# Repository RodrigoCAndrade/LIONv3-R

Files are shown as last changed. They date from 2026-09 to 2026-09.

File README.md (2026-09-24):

<div align="center">
  Rodrigo Andrade Logo
</div>

<h1 align="center">LIONv3-R Module</h1>

<p align="center">
    
    
    
    
    
</p>

<br>

<p align="center">
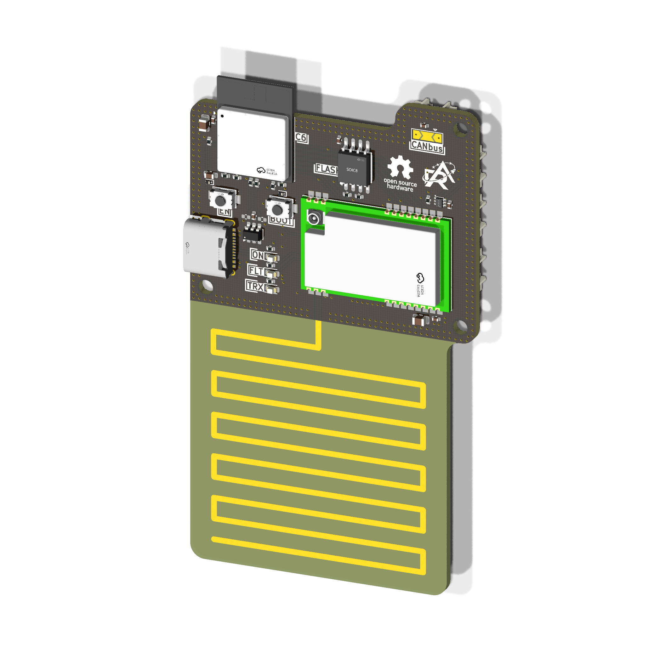
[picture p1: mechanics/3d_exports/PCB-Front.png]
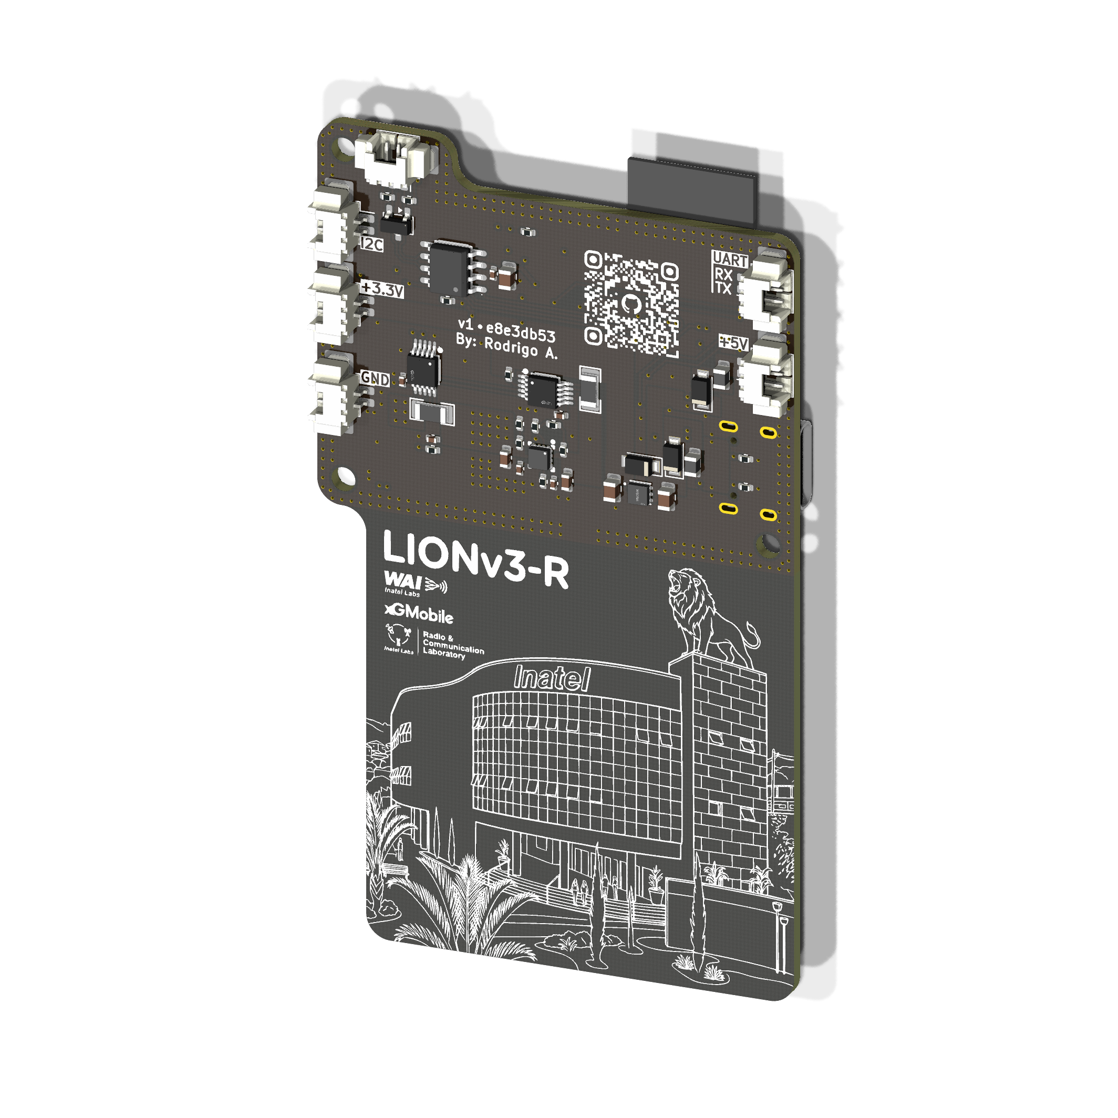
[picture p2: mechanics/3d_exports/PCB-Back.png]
    
</p>

## Overview

The LIONv3-R is an IoT and Direct-to-Satellite (DtS) board built around the ESP32-C6, with 16 MB of external flash and local connectivity over Wi-Fi, Zigbee and Thread. Its radio supports LR-FHSS alongside conventional LoRa, enabling reliable uplinks to satellites or terrestrial gateways from remote sites, at device densities conventional LoRa cannot sustain. By bridging local wireless networks with satellite reach, the LIONv3-R is a complete, scalable hardware platform for telemetry, global asset tracking and remote sensing.

## Repository Organization

* `docs`: Systems engineering, datasheets, requirements (SRD), and interface control (ICD).
* `hardware`: Native KiCad project, schematics, and manufacturing files.
* `mechanics`: 3D models, technical drawings, and physical integration constraints.
* `software`: Embedded firmware and support testing scripts.

## Releases

<table>
  <thead>
    <tr>
      <th>Render</th>
      <th>Hardware Revision</th>
      <th>Status</th>
      <th>Latest Release</th>
      <th>Date</th>
      <th>Datasheet</th>
      <th>BOM</th>
      <th>Manufacturing Info</th>
    </tr>
  </thead>
  <tbody>
    <tr>
      <td>board render</td>
      <td>LIONv3-R</td>
      <td>🚧 Development</td>
      <td><a href="#">-</a></td>
      <td>18-08-2026</td>
      <td><a href="#">PDF</a></td>
      <td>-</td>
      <td><a href="#">Gerber</a></td>
    </tr>
  </tbody>
</table>

## Contributing

We welcome contributions to this project! To ensure a smooth collaboration and maintain our engineering standards, please review our [Contribution Guidelines](CONTRIBUTING.md) before opening any issues, modifying the hardware design, or submitting pull requests.

## References

This board was developed from scratch, but draws on the earlier LIONv1 and LIONv2 designed by [Diego Anestor Coutinho](https://github.com/DIEGOVZK) and [Arielli Ajudarte](https://github.com/ari-aju). The v3 introduces several improvements:

- Dedicated low-power MCU on board
- LR-FHSS support and a more capable LoRa transceiver, covering both sub-GHz and S-band
- External flash for store-and-forward applications
- More efficient antenna
- More compact form factor

## License

This project utilizes a dual-licensing approach to maximize flexibility and adoption:

* **Hardware:** The hardware designs and schematics are licensed under the permissive **[CERN-OHL-P-2.0](hardware/LICENSE)** open-hardware license. You are entirely free to use, modify, distribute, and commercialize the design without any copyleft obligations to share your derived works under the same terms.
* **Software:** All embedded firmware and utility scripts are licensed under the **[MIT License](software/LICENSE)**. You are free to use, modify, and distribute the code without restriction, provided the original copyright notice and permission notice are included.

## Acknowledgments

This work was carried out at the National Institute of Telecommunications (Inatel) with the support of three research laboratories. The EMBRAPII Inatel Competence Center for 5G and 6G Networks [(xGMobile)](https://inatel.br/xgmobile/) supported this project through its Talent Development Program (PFT xGMobile), alongside the Radio & Communication Laboratory [(RadioCom Lab)](https://inatel.br/radiocomlab/) and the Wireless and Artificial Intelligence Laboratory [(WAI Lab)](https://inatel.br/wailab/). Many thanks to the researchers and staff of all three laboratories for their help and for the infrastructure that made the LIONv3-R possible.

<p align="center">
  Funding
</p>

<p align="center">
  <sub>Built with ❤️ by <a href="https://rodrigoandrade.com">Rodrigo de Carvalho Andrade</a></sub>
</p>

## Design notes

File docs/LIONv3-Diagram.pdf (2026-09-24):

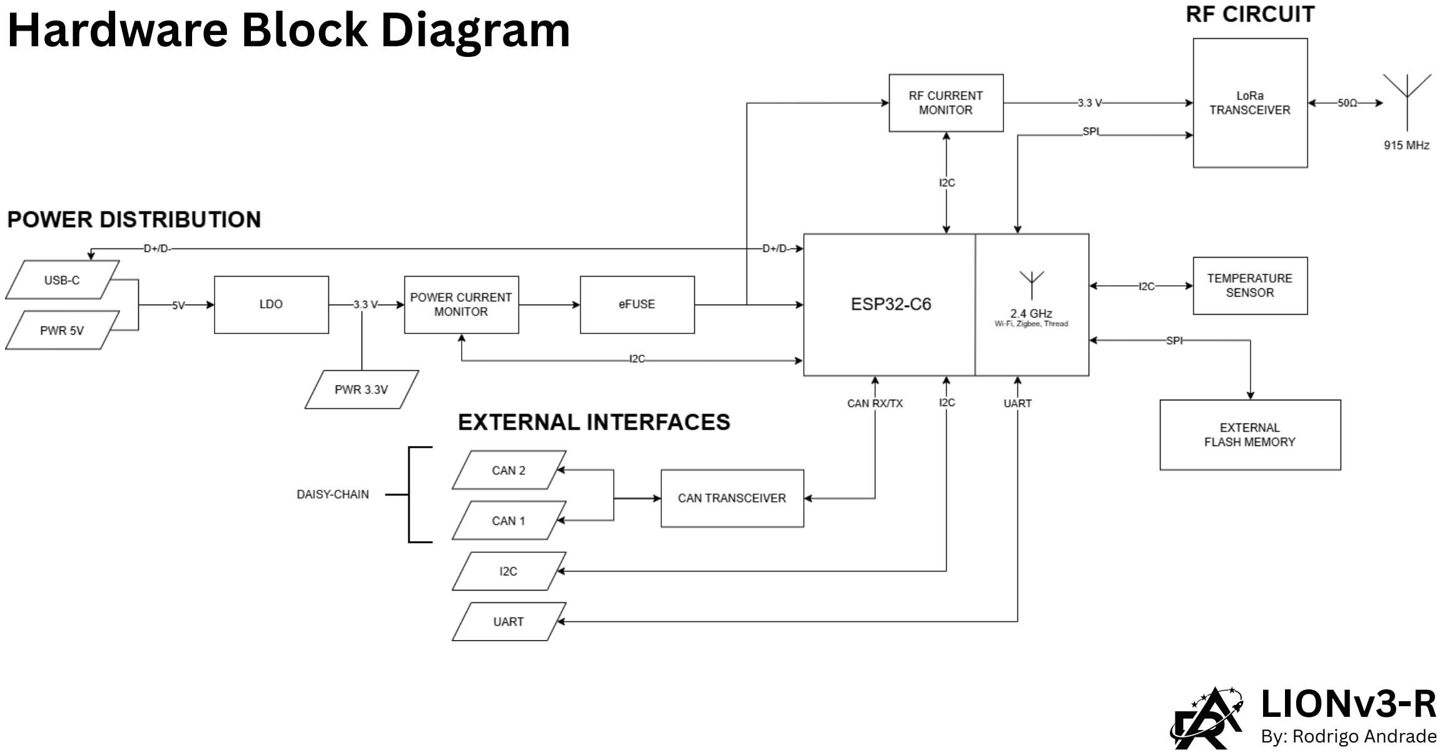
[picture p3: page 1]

LIONv3-R

By: Rodrigo Andrade

Hardware Block Diagram

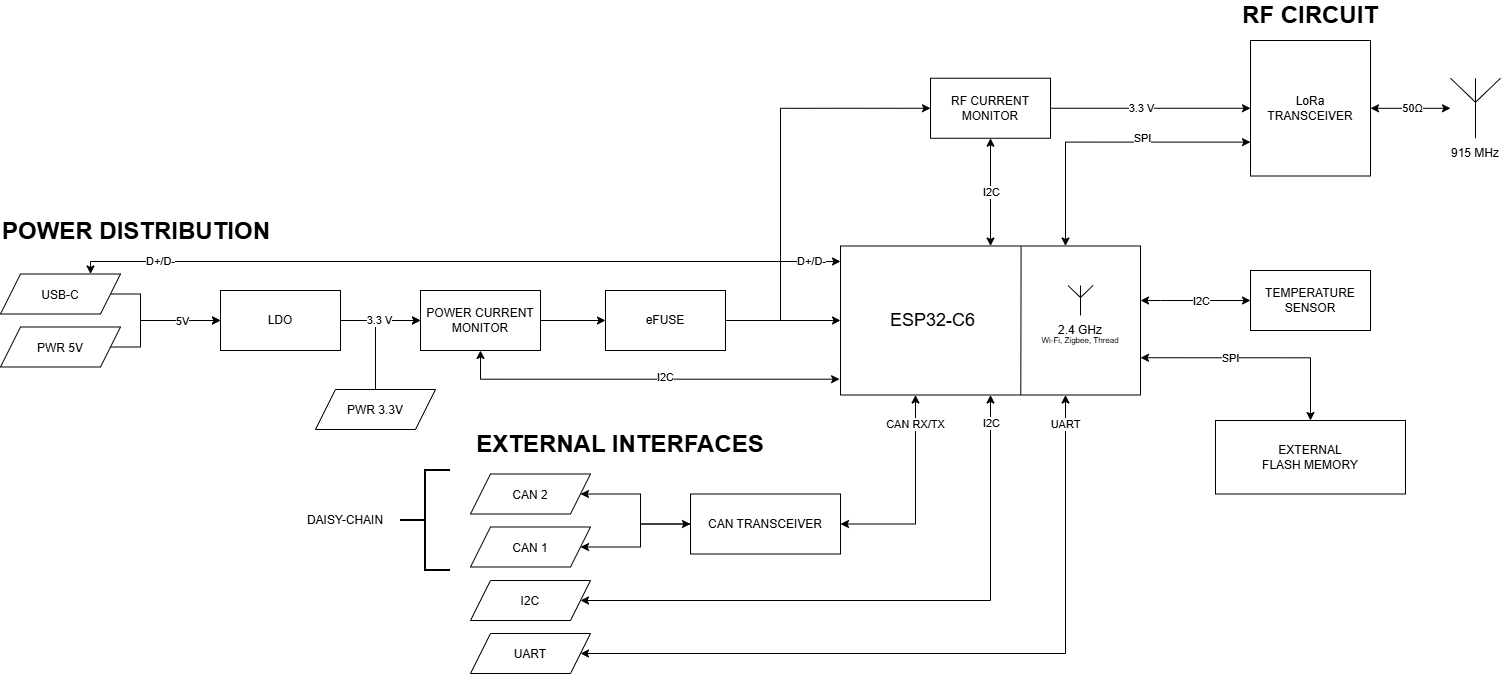
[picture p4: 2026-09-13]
docs/LIONv3-Diagram.png

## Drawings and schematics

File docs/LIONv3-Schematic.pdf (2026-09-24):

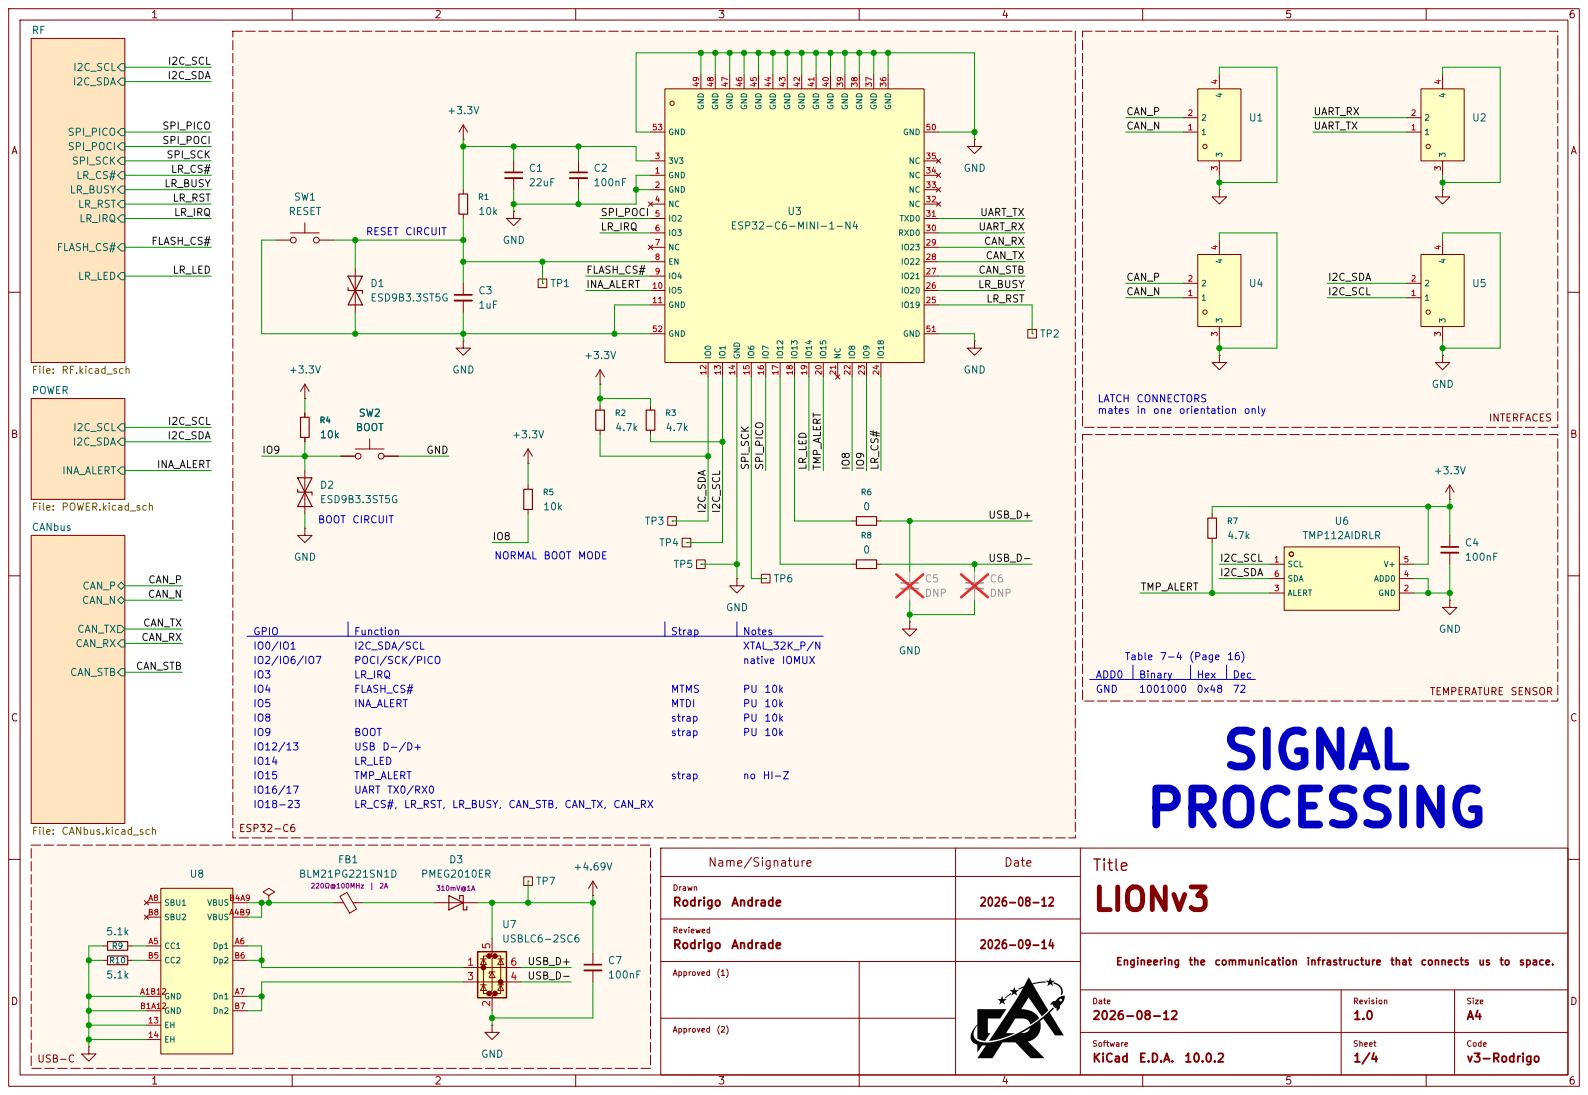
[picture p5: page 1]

LATCH CONNECTORS mates in one orientation only

Drawn Reviewed Rodrigo Andrade | 2026-08-12

Rodrigo Andrade | 2026-09-14

Engineering the communication infrastructure that connects us to space. Code v3-Rodrigo

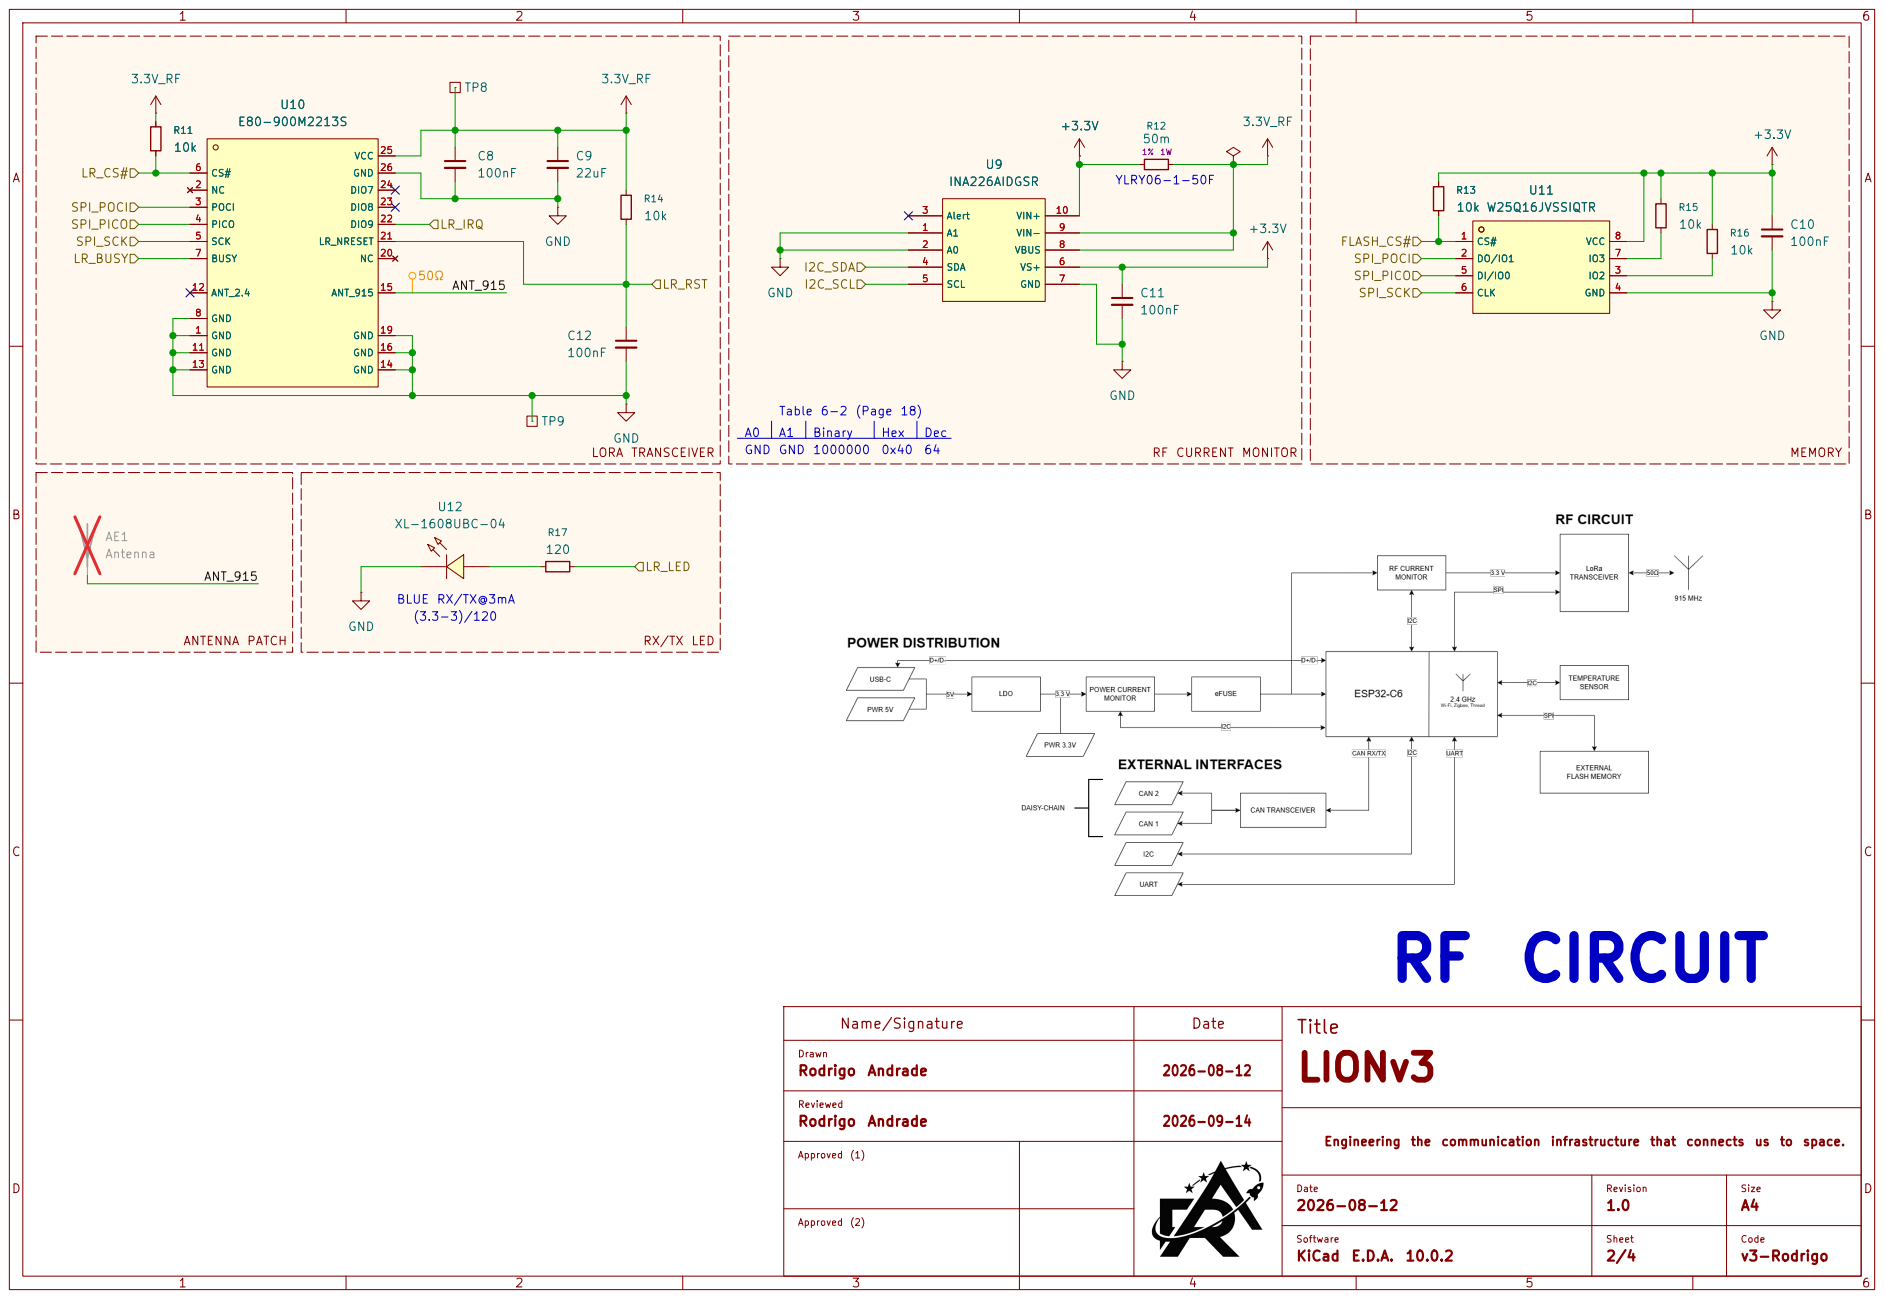
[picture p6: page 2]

Name/Signature | Date | LIONv3 | D Title

Drawn Reviewed Rodrigo Andrade | 2026-08-12

Rodrigo Andrade | 2026-09-14

Engineering the communication infrastructure that connects us to space. Code v3-Rodrigo

Approved (1) Approved (2)

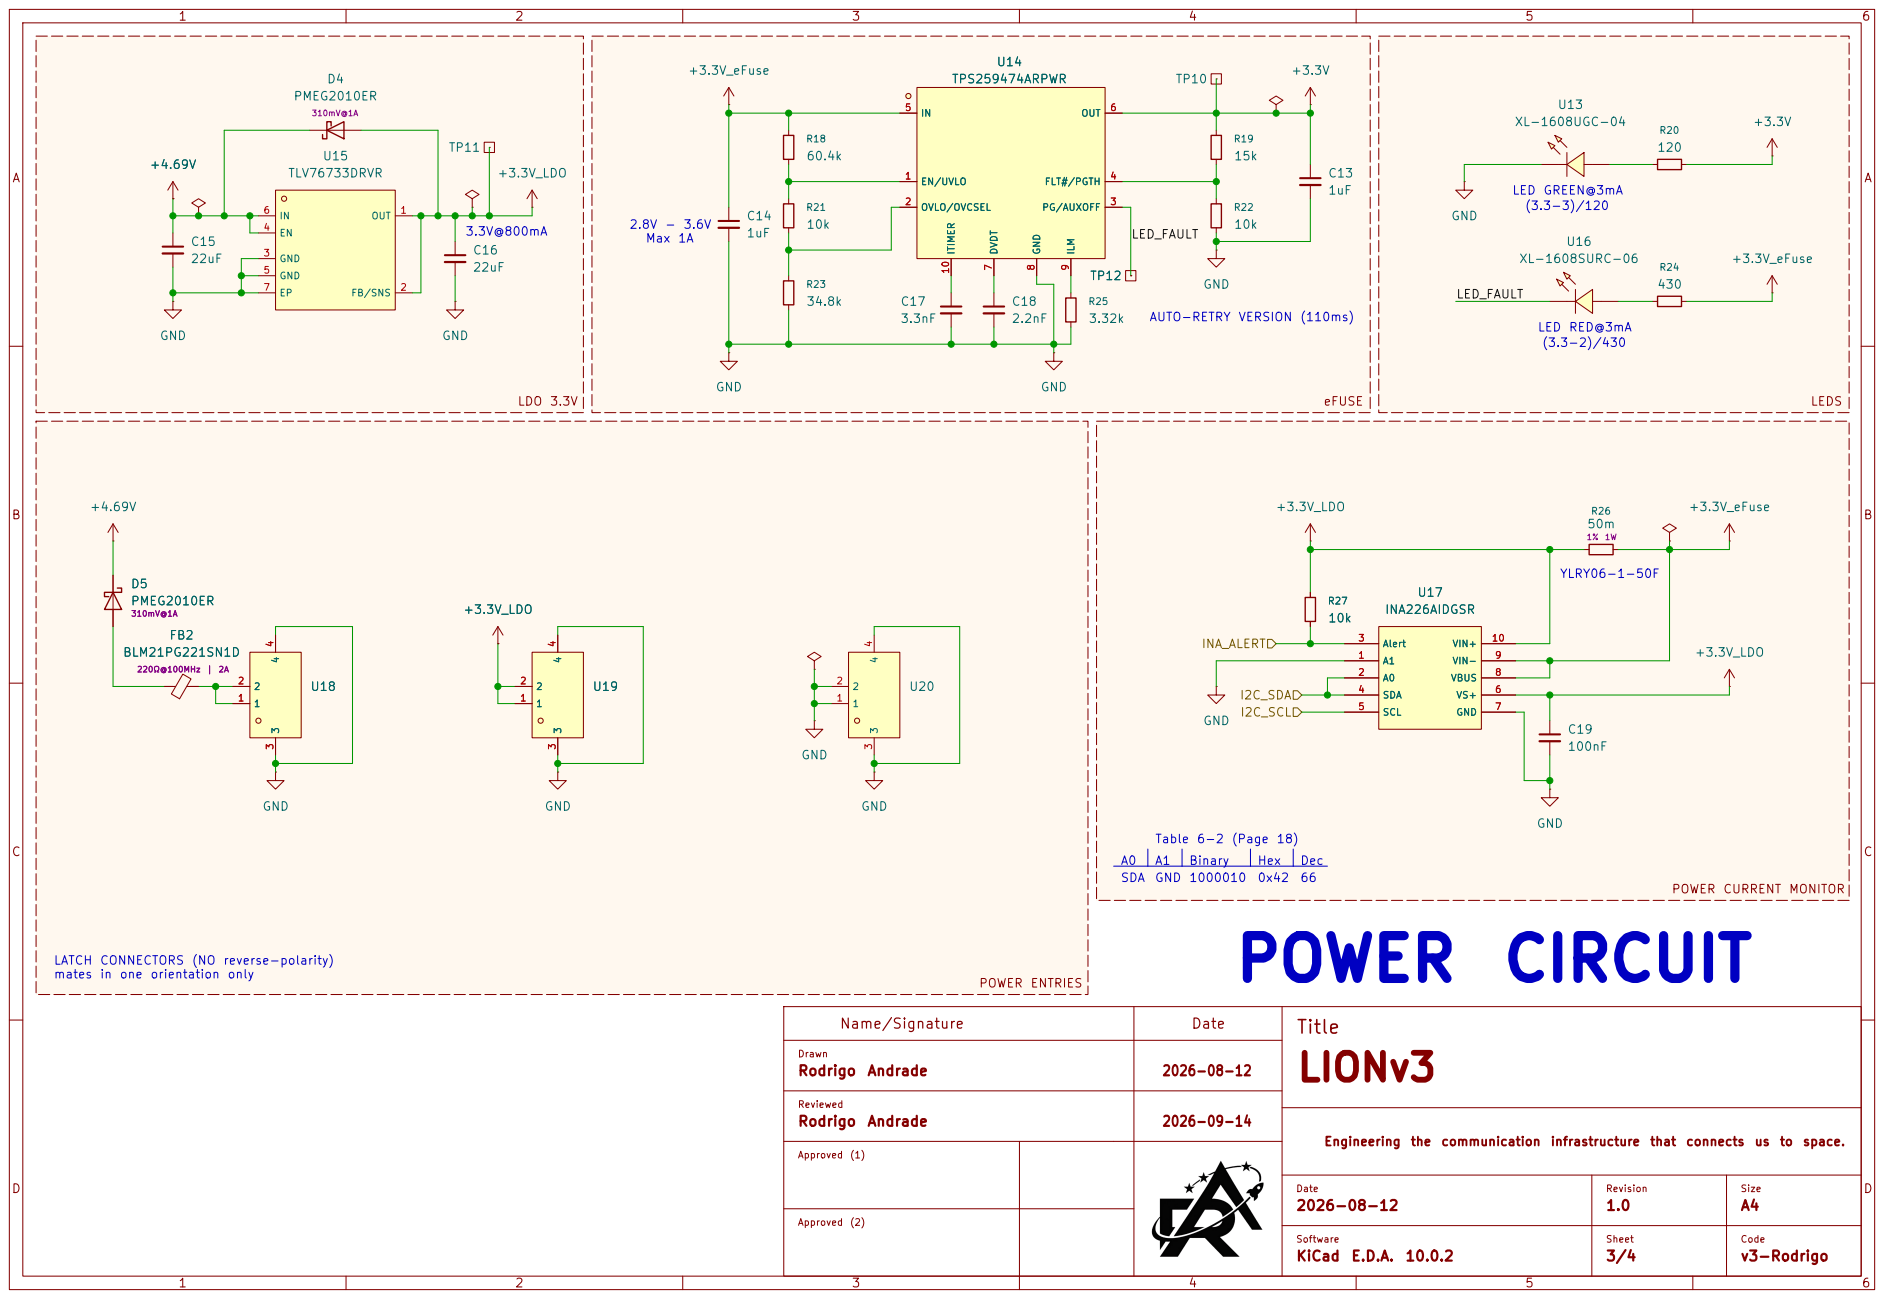
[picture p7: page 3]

LATCH CONNECTORS (NO reverse-polarity) mates in one orientation only

Name/Signature | Date | LIONv3 | D Title

Drawn Reviewed Rodrigo Andrade | 2026-08-12

Rodrigo Andrade | 2026-09-14

Engineering the communication infrastructure that connects us to space. Code v3-Rodrigo

Approved (1) Approved (2)

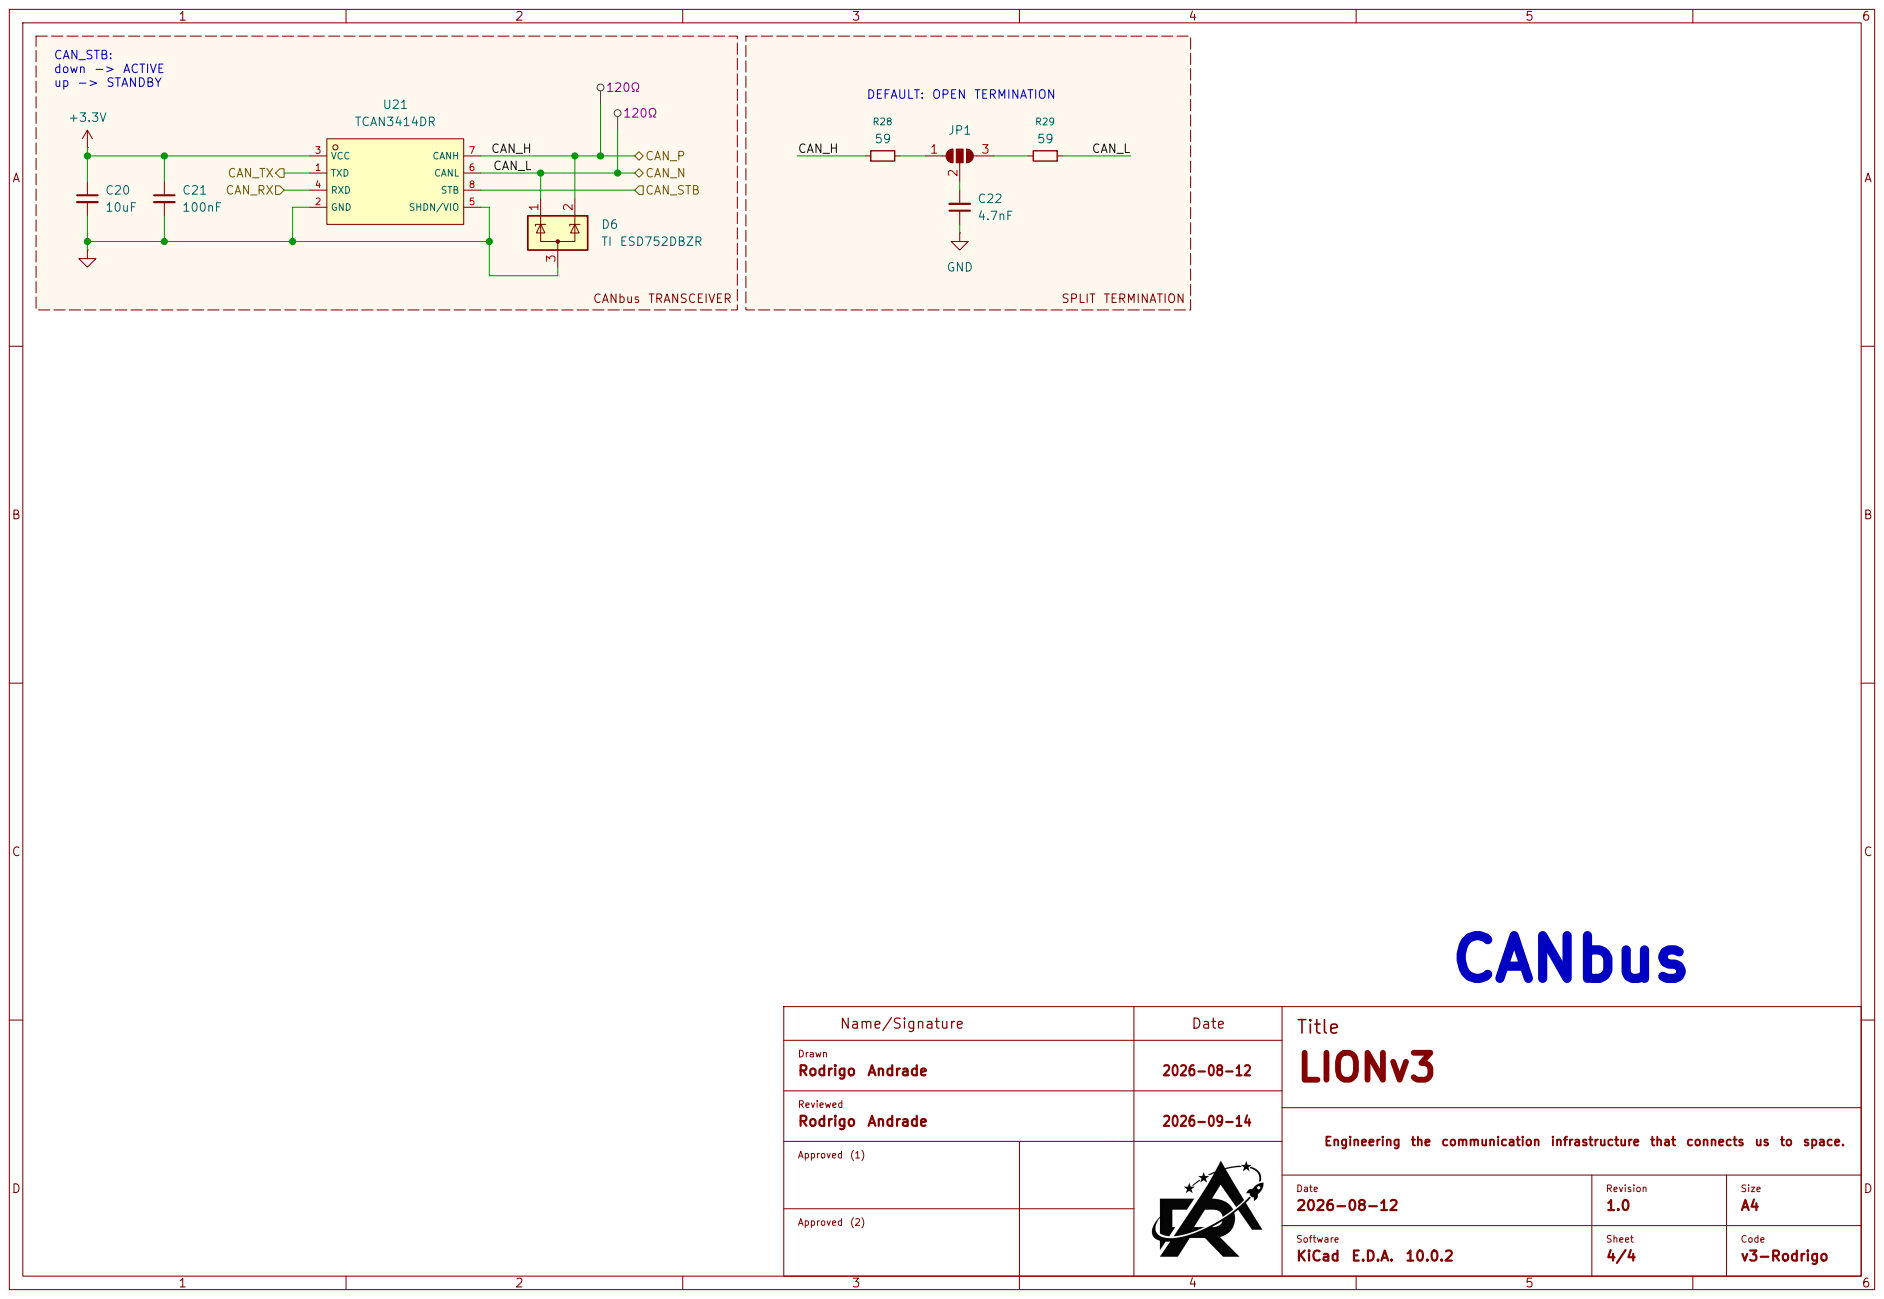
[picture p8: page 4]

Name/Signature | Date | LIONv3 | D Title

Drawn Reviewed Rodrigo Andrade | 2026-08-12

Rodrigo Andrade | 2026-09-14

Engineering the communication infrastructure that connects us to space. Code v3-Rodrigo

Approved (1) Approved (2)

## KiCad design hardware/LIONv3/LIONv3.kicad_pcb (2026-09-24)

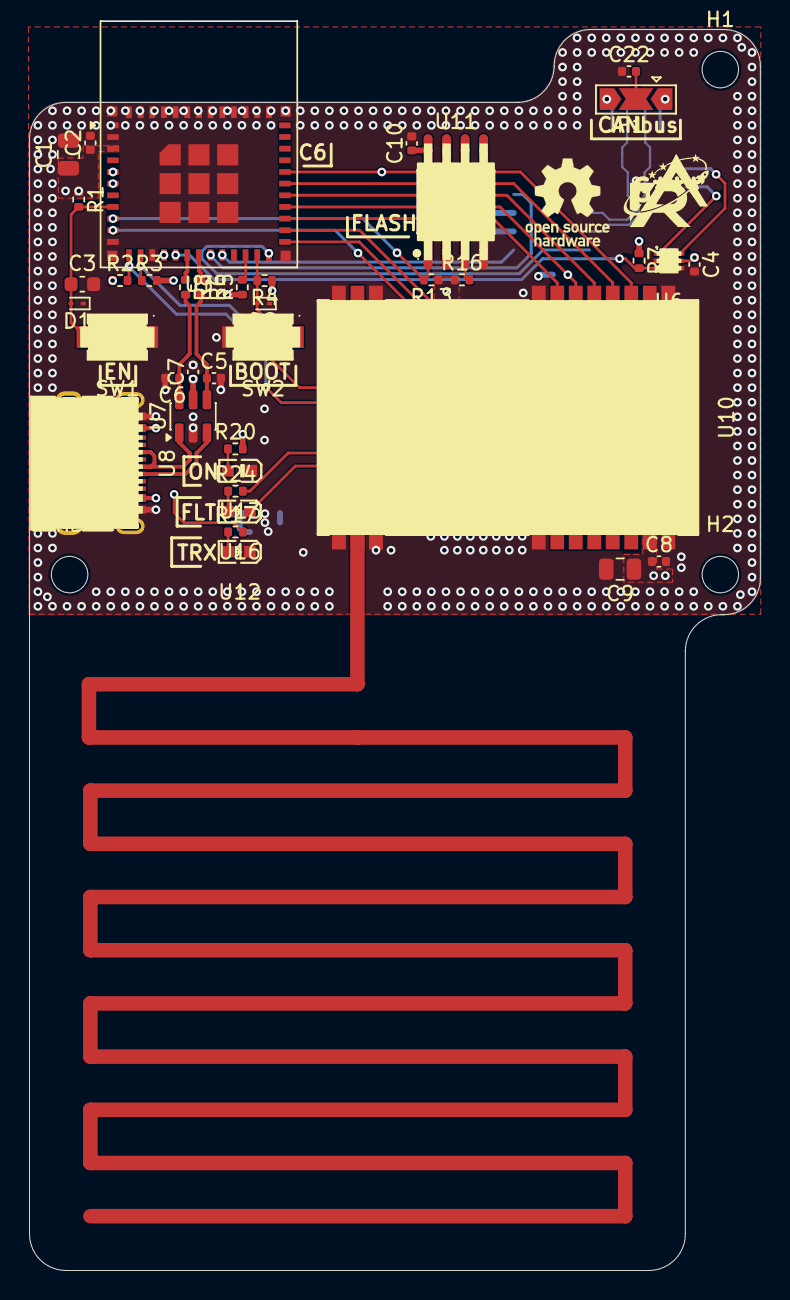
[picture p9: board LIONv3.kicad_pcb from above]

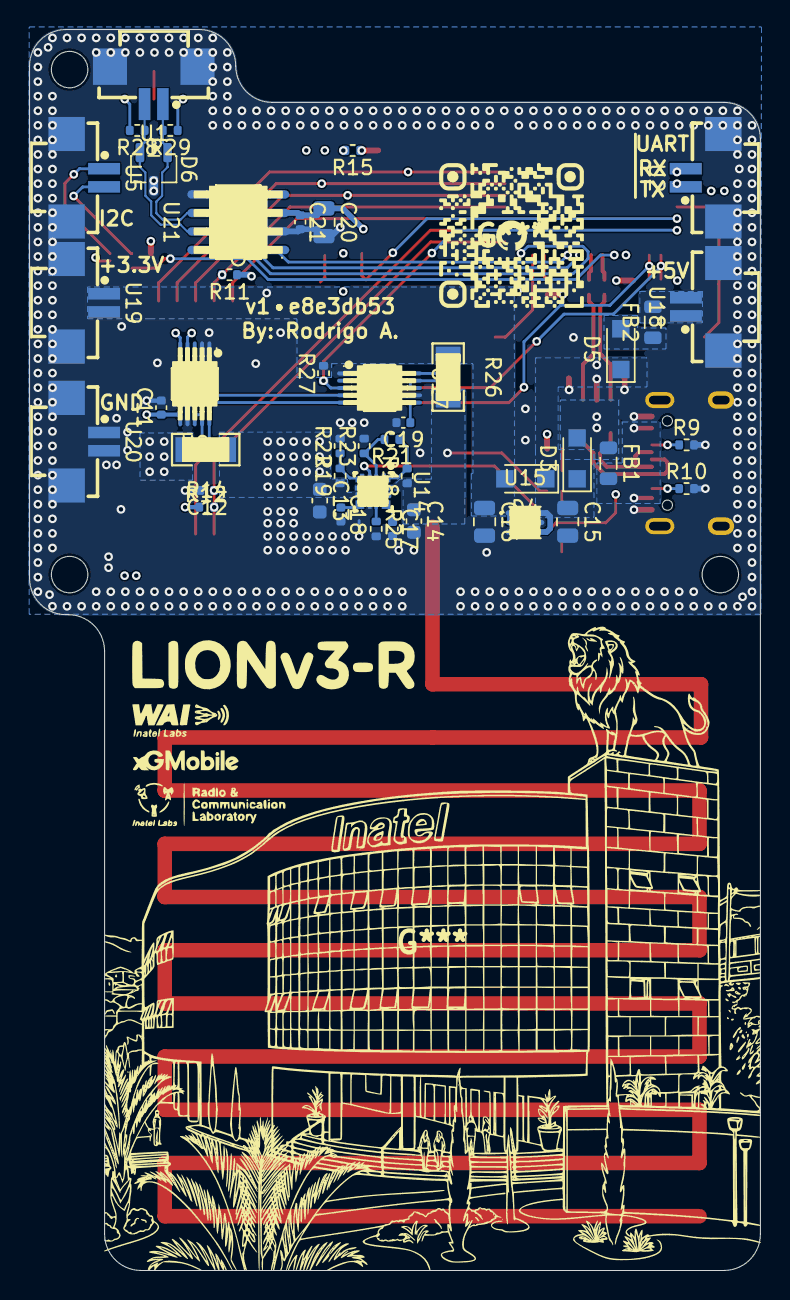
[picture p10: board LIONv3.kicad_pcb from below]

Board: 4 copper layers, 50.1 x 85.2 mm, 85 parts (44 on the bottom side), 56 nets.

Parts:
C1, C9, C15, C16: 22uF; C_0805_2012Metric
C2, C4, C7, C8, C10, C11, C12, C19, C21: 100nF; C_0402_1005Metric
C3, C13, C14: 1uF; C_0603_1608Metric
C5, C6: DNP; C_0402_1005Metric
C17: 3.3nF; C_0402_1005Metric
C18: 2.2nF; C_0402_1005Metric
C20: 10uF; C_0805_2012Metric
C22: 4.7nF; C_0402_1005Metric
D1, D2: ESD9B3.3ST5G; D_SOD-923
D3, D4, D5: PMEG2010ER; Nexperia_CFP3_SOD-123W
D6: TI ESD752DBZR; SOT-23-3
FB1, FB2: BLM21PG221SN1D; L_0805_2012Metric
H1, H2, H3: MountingHole_Pad; MountingHole_2.5mm
JP1: SolderJumper_3_Open; SolderJumper-3_P2.0mm_Open_TrianglePad1.0x1.5mm
R1, R4, R5, R11, R13, R14, R15, R16, R21, R22, R27: 10k; R_0402_1005Metric
R2, R3, R7: 4.7k; R_0402_1005Metric
R6, R8: 0; R_0402_1005Metric
R9, R10: 5.1k; R_0402_1005Metric
R12, R26: 50m; R1206
R17, R20: 120; R_0402_1005Metric
R18: 60.4k; R_0402_1005Metric
R19: 15k; R_0402_1005Metric
R23: 34.8k; R_0402_1005Metric
R24: 430; R_0402_1005Metric
R25: 3.32k; R_0402_1005Metric
R28, R29: 59; R_0402_1005Metric
SW1: RESET; KEY-SMD_L3.9-W3.0-LS5.0
SW2: BOOT; KEY-SMD_L3.9-W3.0-LS5.0
U1, U2, U5, U18, U19, U20: HC-1_25-2PWT; CONN-SMD_2P-P1.25-HC-1.25-2PWT
U3: ESP32-C6-MINI-1-N4; ESP32-C6-MINI-1
U6: TMP112AIDRLR; SOT-563_L1.6-W1.2-P0.50-LS1.6-BR
U7: USBLC6-2SC6; SOT-23-6
U8: TYPE-C_16PIN_2MD(073); USB-C-SMD_TYPE-C-16PIN-2MD-073
U9, U17: INA226AIDGSR; MSOP-10_L3.0-W3.0-P0.50-LS5.0-BL
U10: E80-900M2213S; WIFIM-SMD_22P-L26.0-W16.0-P1.27-TL
U11: W25Q16JVSSIQTR; SOIC-8_L5.3-W5.3-P1.27-LS8.0-BL
U12: XL-1608UBC-04; LED0603-RD_BLUE
U13: XL-1608UGC-04; LED0603-RD_GREEN
U14: TPS259474ARPWR; VQFN-10_L2.0-W2.0-P0.45-TL
U15: TLV76733DRVR; WSON-6_L2.0-W2.0-P0.65-TL-EP
U16: XL-1608SURC-06; LED0603-RD_RED
U21: TCAN3414DR; SOIC-8_L4.9-W3.9-P1.27-LS6.0-BL

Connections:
3.3V_RF: C8.1, C9.1, R12.2, R14.1, U9.8 (VBUS), U9.9 (VIN-), U10.25 (VCC)
+3.3V: C1.1, C2.1, C4.1, C10.1, C11.1, C13.1, C20.1, C21.1, R1.1, R2.1, R3.2, R4.1, R5.1, R7.1, R11.1, R12.1, R13.1, R15.1, R16.1, R19.1, R20.2, U3.3 (3V3), U6.5 (V+), U9.6 (VS+), U9.10 (VIN+), U11.8 (VCC), U14.6 (OUT), U21.3 (VCC)
+3.3V_LDO: C16.1, C19.1, D4.2 (A), R26.1, R27.2, U15.1 (OUT), U15.2 (FB/SNS), U17.6 (VS+), U17.10 (VIN+), U19.1, U19.2
+3.3V_eFuse: C14.1, R18.1, R24.2, R26.2, U14.5 (IN), U17.8 (VBUS), U17.9 (VIN-)
+4.69V: C7.1, C15.1, D3.1 (K), D4.1 (K), D5.1 (K), U7.5 (VBUS), U15.4 (EN), U15.6 (IN)
/CAN_N: D6.1 (K), R29.2, U1.1, U21.6 (CANL)
/CAN_P: D6.2 (K), R28.1, U1.2, U21.7 (CANH)
/CAN_RX: U3.19 (IO14), U21.4 (RXD)
/CAN_STB: U3.24 (IO18), U21.8 (STB)
/CAN_TX: U3.20 (IO15), U21.1 (TXD)
/D+: U7.3 (I/O2), U8.A6 (Dp1), U8.B6 (Dp2)
/D-: U7.1 (I/O1), U8.A7 (Dn1), U8.B7 (Dn2)
/ESP_USB_D+: R6.1, U3.18 (IO13)
/ESP_USB_D-: R8.1, U3.17 (IO12)
/FLASH_CS#: R13.2, U3.9 (IO4), U11.1 (CS#)
/I2C_SCL: R3.1, U3.13 (IO1), U5.2, U6.1 (SCL), U9.5 (SCL), U17.5 (SCL)
/I2C_SDA: R2.2, U3.12 (IO0), U5.1, U6.6 (SDA), U9.4 (SDA), U17.2 (A0), U17.4 (SDA)
/INA_ALERT: R27.1, U3.10 (IO5), U17.3 (Alert)
/IO8: R5.2, U3.22 (IO8)
/IO9: D2.2 (A2), R4.2, SW2.1, U3.23 (IO9)
/LR_BUSY: U3.27 (IO21), U10.7 (BUSY)
/LR_CS#: R11.2, U3.28 (IO22), U10.6 (CS#)
/LR_IRQ: U3.26 (IO20), U10.22 (DIO9)
/LR_LED: R17.2, U3.15 (IO6)
/LR_RST: C12.1, R14.2, U3.25 (IO19), U10.21 (LR_NRESET)
/POWER/LED_FAULT: U14.3 (PG/AUXOFF), U16.1 (K)
/SPI_PICO: U3.30 (RXD0), U10.4 (PICO), U11.5 (DI/IO0)
/SPI_POCI: U3.31 (TXD0), U10.3 (POCI), U11.2 (DO/IO1)
/SPI_SCK: U3.29 (IO23), U10.5 (SCK), U11.6 (CLK)
/TMP_ALERT: R7.2, U3.16 (IO7), U6.3 (ALERT)
/UART_RX: U2.2, U3.5 (IO2)
/UART_TX: U2.1, U3.6 (IO3)
/USB_D+: C5.1, R6.2, U7.4 (I/O2)
/USB_D-: C6.1, R8.2, U7.6 (I/O1)
GND: C1.2, C2.2, C3.2, C4.2, C5.2, C6.2, C7.2, C8.2, C9.2, C10.2, C11.2, C12.2, C13.2, C14.2, C15.2, C16.2, C17.2, C18.2, C19.2, C20.2, C21.2, C22.1, D1.1 (A1), D2.1 (A1), D6.3 (A), R9.2, R10.2, R22.2, R23.2, R25.2, SW1.1, SW2.2, U1.3, U1.4, U2.3, U2.4, U3.1 (GND), U3.2 (GND), U3.11 (GND), U3.14 (GND), U3.36 (GND), U3.37 (GND), U3.38 (GND), U3.39 (GND), U3.40 (GND), U3.41 (GND), U3.42 (GND), U3.43 (GND), U3.44 (GND), U3.45 (GND), U3.46 (GND), U3.47 (GND), U3.48 (GND), U3.49 (GND), U3.50 (GND), U3.51 (GND), U3.52 (GND), U3.53 (GND), U5.3, U5.4, U6.2 (GND), U6.4 (ADD0), U7.2 (GND), U8.13 (EH), U8.14 (EH), U8.A1B12 (GND), U8.B1A12 (GND), U9.1 (A1), U9.2 (A0), U9.7 (GND), U10.1 (GND), U10.8 (GND), U10.11 (GND), U10.13 (GND), U10.14 (GND), U10.16 (GND), U10.19 (GND), U10.26 (GND), U11.4 (GND), U12.1 (K), U13.1 (K), U14.8 (GND), U15.3 (GND), U15.5 (GND), U15.7 (EP), U17.1 (A1), U17.7 (GND), U18.3, U18.4, U19.3, U19.4, U20.1, U20.2, U20.3, U20.4, U21.2 (GND), U21.5 (SHDN/VIO)
unnamed: C3.1, D1.2 (A2), R1.2, SW1.2, U3.8 (EN)
unnamed: D3.2 (A), FB1.1
unnamed: D5.2 (A), FB2.1
unnamed: FB1.2, U8.A4B9 (VBUS), U8.B4A9 (VBUS)
unnamed: FB2.2, U18.1, U18.2
unnamed: JP1.1 (A), R28.2
unnamed: JP1.3 (B), R29.1
unnamed: C22.2, JP1.2 (C)
unnamed: R9.1, U8.A5 (CC1)
unnamed: R10.1, U8.B5 (CC2)
unnamed: R16.2, U11.3 (IO2)
unnamed: R15.2, U11.7 (IO3)
unnamed: R17.1, U12.2 (A)
unnamed: R20.1, U13.2 (A)
unnamed: C18.1, U14.7 (DVDT)
unnamed: R18.2, R21.1, U14.1 (EN/UVLO)
unnamed: R19.2, R22.1, U14.4 (FLT#/PGTH)
unnamed: R25.1, U14.9 (ILM)
unnamed: C17.1, U14.10 (ITIMER)
unnamed: R21.2, R23.1, U14.2 (OVLO/OVCSEL)
unnamed: R24.1, U16.2 (A)

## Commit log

2026-08-12 feat(schematic): start schematic
    [LIONv3.kicad_pcb, LIONv3.kicad_sch]
2026-08-12 feat(hardware): organize schematic pages
    [LIONv3.kicad_pcb, LIONv3.kicad_sch, POWER.kicad_sch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]
2026-08-12 feat(hardware): add ESP32-C6 UART0
    [LIONv3.kicad_sch, RF.kicad_sch]
2026-08-13 feat(hardware): finish ESP32-C6 electrical schematic
    [LIONv3.kicad_pcb, LIONv3.kicad_sch, POWER.kicad_sch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]
2026-08-14 feat(hardware): add MOLEX connectors
    [LIONv3.kicad_pcb, LIONv3.kicad_sch, POWER.kicad_sch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]
2026-08-15 feat(hardware): finish board schematic
    [LIONv3.kicad_pcb, LIONv3.kicad_sch, POWER.kicad_sch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]
2026-08-16 feat(hardware): add TPS259474ARPWR PCB circuit
    [LIONv3.kicad_pcb, POWER.kicad_sch, RF.kicad_sch]
2026-08-18 feat(hardware): add TLV76733DRVR circuit
    [LIONv3.kicad_pcb, POWER.kicad_sch, RF.kicad_sch]
2026-08-18 feat(hardware): PCB macro placement
    [LIONv3.kicad_pcb, LIONv3.kicad_sch]
2026-08-18 feat(hardware): add final components position
    [LIONv3.kicad_pcb, LIONv3.kicad_sch, POWER.kicad_sch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]
2026-08-18 feat(hardware): organize repo structure
    [LIONv3.kicad_pcb, LIONv3.kicad_sch, RF.kicad_sch]
2026-08-19 feat(hardware): add power layout
    [LIONv3.kicad_pcb, LIONv3.kicad_sch, POWER.kicad_sch]
2026-08-20 feat(hardware): add RF circuit
    [LIONv3.kicad_pcb]
2026-09-01 Add TVS diode protection (ESD9B3.3ST5G)
    [LIONv3.kicad_sch, POWER.kicad_sch, RF.kicad_sch]
2026-09-01 feat(hardware): Add TVS diode protection on USB lines (USBLC6-2SC6)
    [LIONv3.kicad_sch, POWER.kicad_sch]
2026-09-02 feat(hardware): Add Ferrite Bead to VBUS line
    [LIONv3.kicad_sch]
2026-09-02 feat(hardware): Add ORing (USB VBUS back-feed)
    [LIONv3.kicad_sch, POWER.kicad_sch]
2026-09-08 feat(hardware): improves LED series currents
    [POWER.kicad_sch, RF.kicad_sch]
2026-09-09 feat(hardware): removes R1 and C3 from reset switch
    [LIONv3.kicad_sch, POWER.kicad_sch]
2026-09-09 feat(hardware): change SPI terminology (new OSHWA naming conventions)
    [LIONv3.kicad_pcb, LIONv3.kicad_sch, POWER.kicad_sch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]
2026-09-09 feat(hardware): add shunt resistor rating to schematic
    [POWER.kicad_sch, RF.kicad_sch]
2026-09-09 feat(hardware): annotate schematic with I2C addresses
    [LIONv3.kicad_sch, POWER.kicad_sch, RF.kicad_sch]
2026-09-09 fix(hardware): fix CANbus split termination
    [CANbus.kicad_sch, LIONv3.kicad_sch]
2026-09-11 refactor(hardware): reorganize schematic
    [CANbus.kicad_sch, LIONv3.kicad_sch, POWER.kicad_sch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]
2026-09-11 refactor(hardware): add MPN diodes and ferrite beads
    [LIONv3.kicad_sch, POWER.kicad_sch]
2026-09-11 refactor(hardware): rename power symbols
    [LIONv3.kicad_sch, POWER.kicad_sch]
2026-09-11 feat(hardware): change LDO capacitors from 2.2uF to 22uF
    [POWER.kicad_sch]
2026-09-11 feat(hardware): major schematic improvements
    [LIONv3.kicad_sch, POWER.kicad_sch, RF.kicad_sch]
2026-09-11 feat(hardware): change schotkky diode to PMEG2010ER
    [LIONv3.kicad_sch, POWER.kicad_sch]
2026-09-12 feat(hardware): add pre-review schematic
    [CANbus.kicad_sch, LIONv3.kicad_sch, POWER.kicad_sch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]
2026-09-14 feat(hardware): add TestPoints
    [CANbus.kicad_sch, LIONv3.kicad_pcb, LIONv3.kicad_sch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]
2026-09-15 feat(hardware): start PCB design
    [CANbus.kicad_sch, LIONv3.kicad_pcb, LIONv3.kicad_sch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]
2026-09-16 feat(hardware): add board form-factor
    [LIONv3.kicad_pcb, LIONv3.kicad_sch]
2026-09-16 refactor(hardware): improve via fencing
    [LIONv3.kicad_pcb, LIONv3.kicad_sch]
2026-09-16 feat(hardware): add LED layout
    [LIONv3.kicad_pcb, LIONv3.kicad_sch]
2026-09-17 feat(hardware): start PDN design
    [LIONv3.kicad_pcb]
2026-09-19 refactor(hardware): update board render preview
2026-09-20 feat(hardware): improve PCB layout
    [LIONv3.kicad_pcb, LIONv3.kicad_sch]
2026-09-21 feat(hardware): finish PDN
    [LIONv3.kicad_pcb, LIONv3.kicad_sch]
2026-09-22 feat(hardware): route USB-C and CANbus differential pairs
    [CANbus.kicad_sch, LIONv3.kicad_pcb, LIONv3.kicad_sch]
2026-09-23 feat(hardware): finish main routing
    [LIONv3.kicad_pcb, LIONv3.kicad_sch, RF.kicad_sch]
2026-09-24 feat(hardware): complete 90% of PCB layout, final tweaks remaining
    [LIONv3.kicad_pcb]
